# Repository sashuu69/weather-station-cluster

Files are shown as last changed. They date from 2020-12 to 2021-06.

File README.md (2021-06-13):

# Weather Station Cluster

## Introduction

The Weather Station Cluster is weather station system for ethusiasts that want to measure data for education and research purposes.

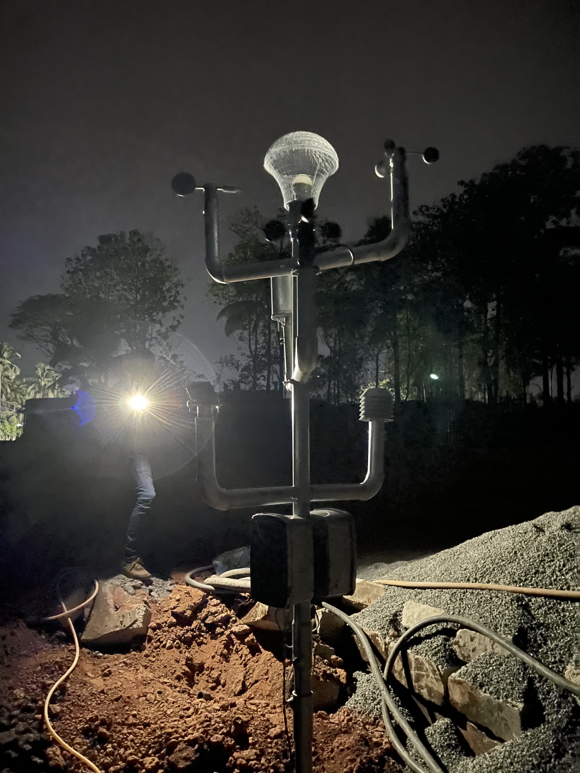
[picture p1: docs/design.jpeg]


## Features

1. The device collects the following data:-
   1. Temperature
   2. Humidity
   3. Heat index
   4. Altitude
   5. Pressure
   6. Rain (in cm)
   7. Rain duration and strength
   8. Wind speed
   9. Wind direction
2. Collects the above mentioned parameters and stores the data to database.

## Folder Structure

1. code/arduino_mega-code: Contains code for Arduino Mega.
2. code/nodemcu-code: Contains code NodeMCU.
3. docs: PCB images (Top, Bottom and Drill).
4. eagle-design: Eagle design of PCB.
5. fusion360-design: STL files of rain guage, wind direction and wind speed.

## Library used

1. DHT22 Library - [GitHub](https://github.com/adafruit/DHT-sensor-library)
2. BMP280 Library - [GitHub](https://github.com/adafruit/Adafruit_BMP280_Library)
3. RTC Library - [GitHub](https://github.com/adafruit/RTClib)
4. ArduinoJSON Library - [GitHub](https://github.com/bblanchon/ArduinoJson)
5. Adafruit Sensor - [github.com](https://github.com/adafruit/Adafruit_Sensor)

## CAD Files

1. Rain sensor support - [Thingiverse](https://www.thingiverse.com/thing:4107951)

## Components Used

1. NodeMCU (x1) - [Tomson Electronics](https://www.tomsonelectronics.com/products/buy-node-mcu-esp-8266-with-cp-2102-online)
2. Micro SD card module (x1) - [Tomson Electronics](https://www.tomsonelectronics.com/products/micro-sd-card-module)
3. Arduino Mega (x1) - [Tomson Electronics](https://www.tomsonelectronics.com/products/buy-arduino-mega-2560-online-india)
4. DHT22 (x1) - [Tomson Electronics](https://www.tomsonelectronics.com/products/dht22-digital-temperature-and-humidity-sensor-module-am2302)
5. BMP 280 (x1) - [Tomson Electronics](https://www.tomsonelectronics.com/products/bmp-280-barometer-precision-atmospheric-pressure-sensor-module)
6. Rain sensor (x1) - [Tomson Electronics](https://www.tomsonelectronics.com/products/rain-drop-detection-sensor-rain-detector-weather-module)
7. Speed Measuring sensor Groove Coupler Module (x1) - [Tomson Electronics](https://www.tomsonelectronics.com/products/speed-measuring-sensor-groove-coupler-module-for-arduino)
8. RTC module (x1) - [Tomson Electronics](https://www.tomsonelectronics.com/products/ds1307-i2c-rtc-ds1307-24c32-real-time-clock-module)
9. Button cell (CR-2032) (x1) - [Tomson Electronics](https://www.tomsonelectronics.com/products/panasonic-cr-2032)
10. Female headers - [Robu (India)](https://robu.in/product/2mm-pitch-female-berg-strip-40x1-2pcs/)
11. Male header pins - [Robu (India)](https://robu.in/product/1x40-berg-strip-male-connector/)
12. DC Barrel Power Jack (x1) - [Tomson Electronics](https://www.tomsonelectronics.com/products/dc-barrel-power-jack)
13. LED (Red) (x4) - [Tomson Electronics](https://www.tomsonelectronics.com/products/led-basic-red-5mm-pack-of-10)
14. Diode IN 4007 (x1) - [Tomson Electronics](https://www.tomsonelectronics.com/products/diode-1n-4007)
15. 7805 5V regulator (x1) - [Amazon (India)](https://www.amazon.in/5-piece-voltage-regulator-7805/dp/0070530572)
16. LED (Green) (x3) - [Tomson Electronics](https://www.tomsonelectronics.com/products/led-basic-green-5-mm)
17. Micro SD Card Module (x1) - [Tomson Electronics](https://www.tomsonelectronics.com/products/micro-sd-card-module)
18. Rain drop detection sensor Module (x1) - [Tomson Electronics](https://www.tomsonelectronics.com/products/rain-drop-detection-sensor-rain-detector-weather-module)
19. Resistor (10K Ohms) (x2) - [Tomson Electronics](https://www.tomsonelectronics.com/products/1ko-12ko-carbon-film-resistor)
20. Resistor (220 Ohms) (x7) - [Tomson Electronics](https://www.tomsonelectronics.com/products/100k-ohm-metal-film-resistor?variant=8737726038107)
21. Neodymium disc magnets (4x1.5mm) (x2) - [Tomson Electronics](https://www.tomsonelectronics.com/products/neodymium-disc-magnets?variant=37753432768707)
22. Neodymium disc magnets (4x1.5mm) (x1) - [Tomson Electronics](https://www.tomsonelectronics.com/products/neodymium-disc-magnets?variant=37753432801475)
23. PLA (1KG) (WHITE) (x1) - [Tomson Electronics](https://www.augment3di.com/product/white-pla-premium-filament-1kg/)
24. Pole, Wires, tapes and zip ties

## PCB design

### Info Board

#### Top View

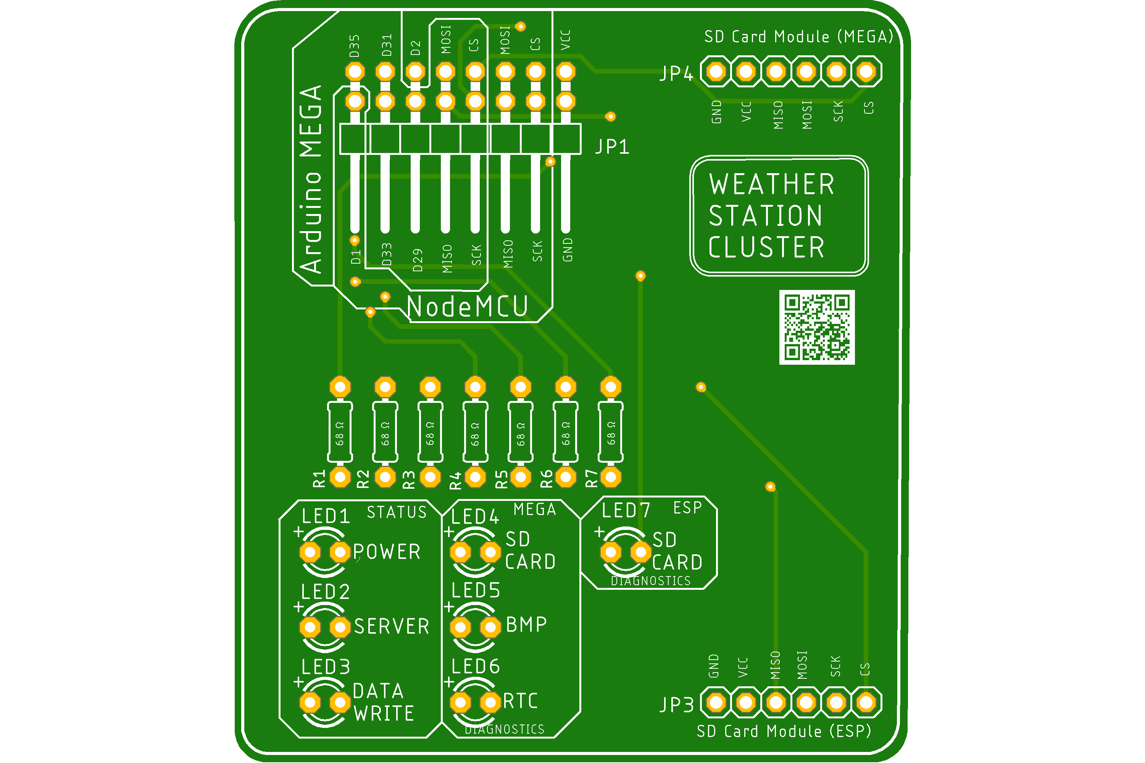
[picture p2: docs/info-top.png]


#### Bottom View

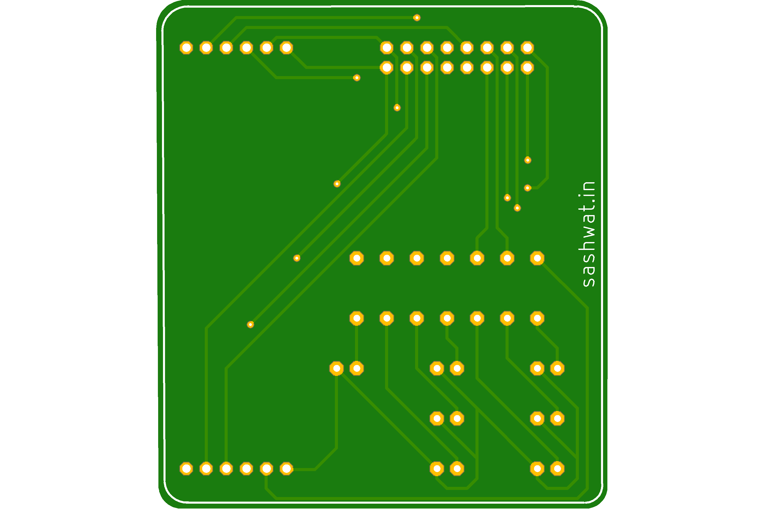
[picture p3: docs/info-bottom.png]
Bottom View


#### Drill View

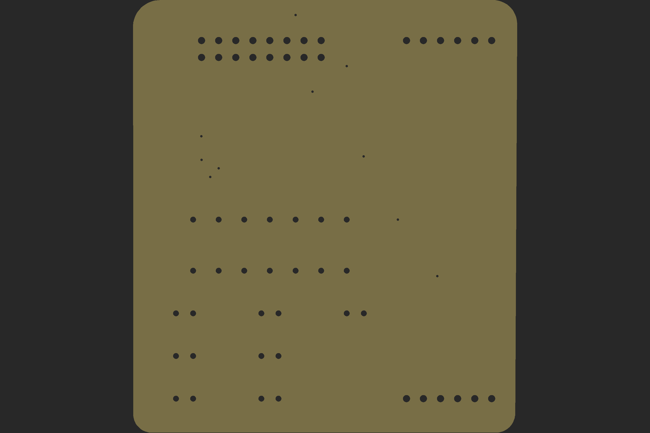
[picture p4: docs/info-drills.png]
Drill View


### Process Board

#### Top View

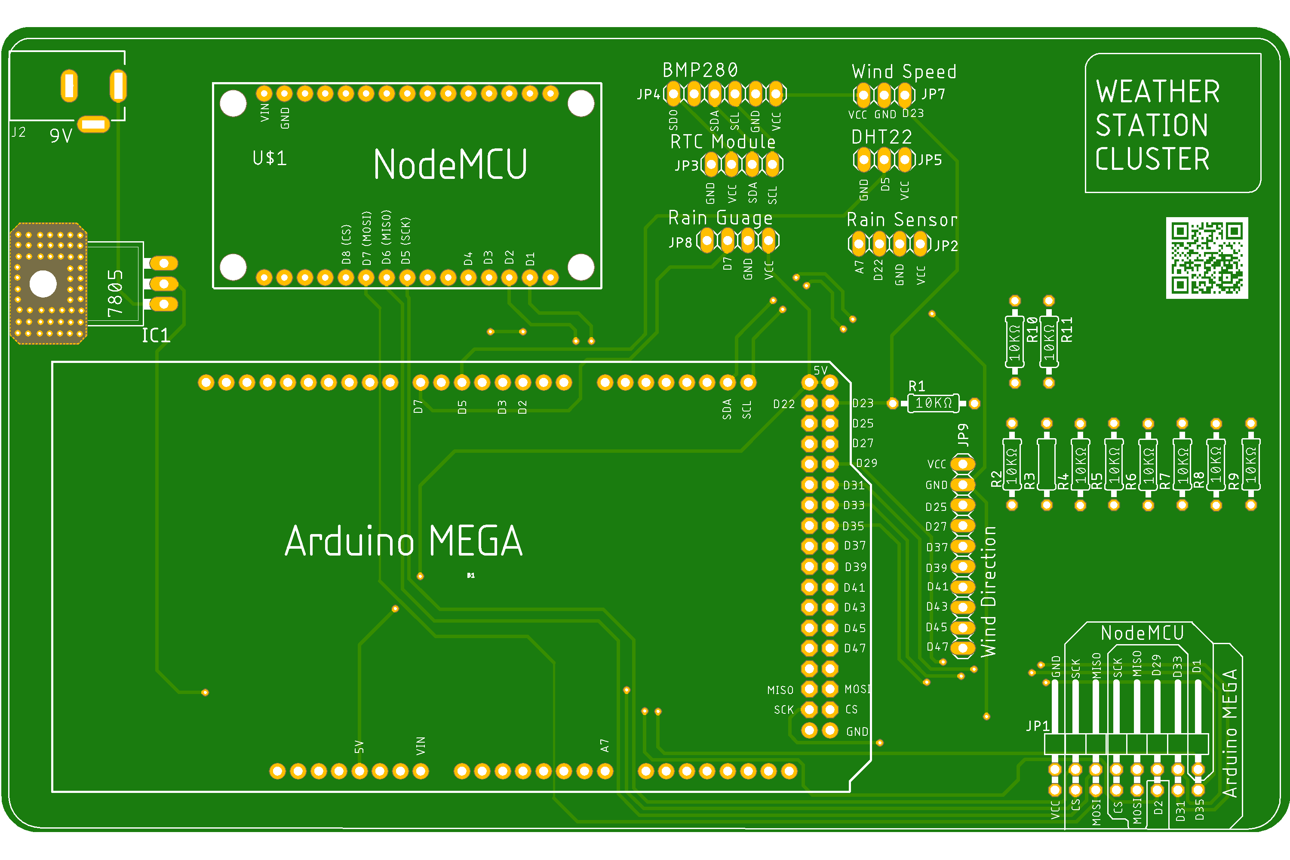
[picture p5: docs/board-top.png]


#### Bottom View

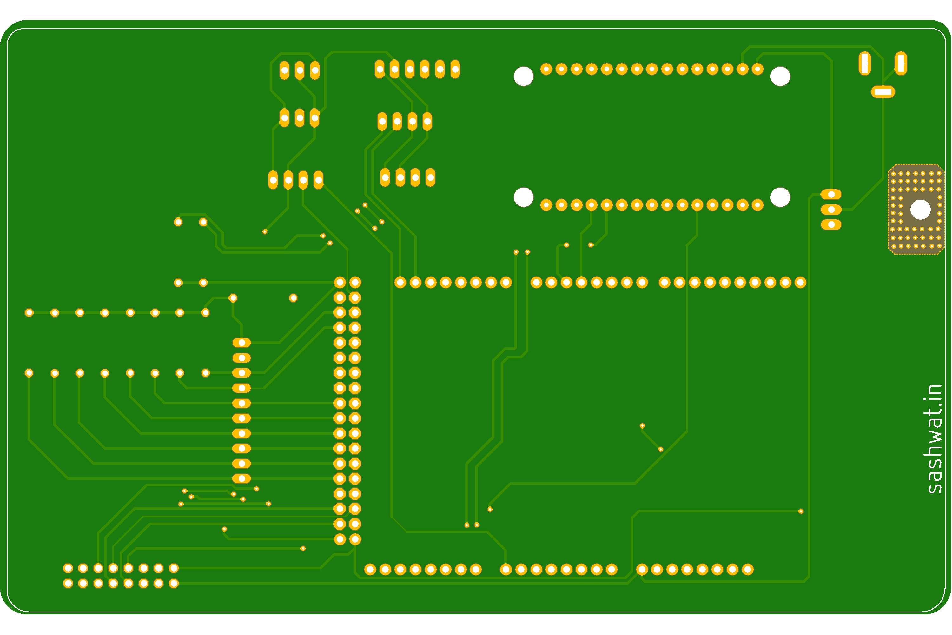
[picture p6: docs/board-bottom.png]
Bottom View


#### Drill View

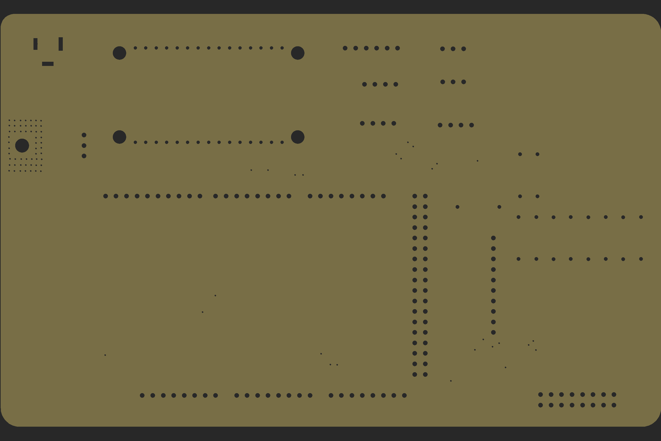
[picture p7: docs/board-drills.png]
Drill View


## Pre-Installation Steps

1. Connect the sensors as per circuit diagram.
2. Flash the NodeMCU code.
3. Connect to NodeMCU WiFi hotspot (SSID: Home Weather Station Mini) WiFi hotspot.
4. Goto http://192.168.4.1 (NodeMCU gateway).
5. Enter WiFi credentials.
6. After connecting to WiFi, use Fing to get IP address of NodeMCU.
7. Goto http://ip-address and enter username (admin) and password (pasword).
8. Enter server IP address, API key and other necessary details.

## Sensor Info

| Sensor name | Features |
| --- | --- |
| DHT22 | Temperature, Humidity and Heat Index |
| BMP280 | Temperature, atmospheric pressure and altitude |
| Rain Guage | Rain in CM |
| Rain drop sensor | Rain Duration and Strength |
| Annemometer | Wind speed and wind direction |

## Contributions

1. Sashwat K (@sashuu6) <hi@sashwat.in>
2. Tharun P Karun (@tharunpkarun) <tpk@tharun.me>
3. Sreeram (STL files) [YouTube](https://www.youtube.com/channel/UC3x_svxO5Dxl0VesjEMpuGg)

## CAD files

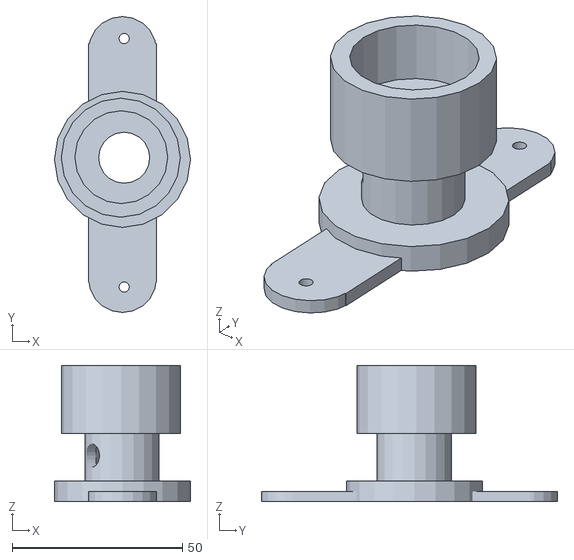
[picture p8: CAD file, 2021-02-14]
fusion360-design/rain-guage/pvc-holder.stl
40.0 x 87.0 x 40.0

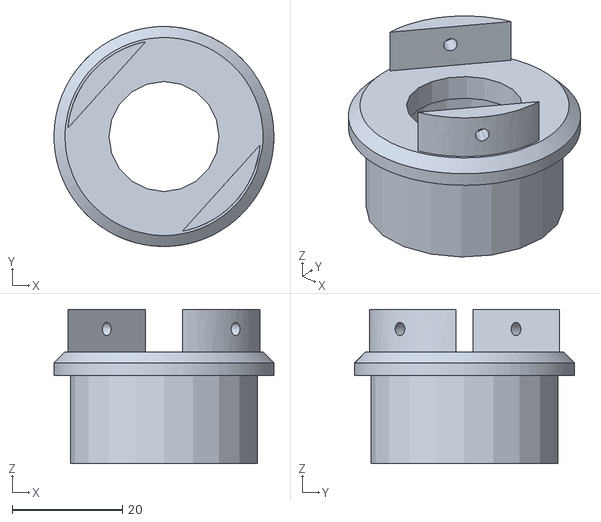
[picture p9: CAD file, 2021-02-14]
fusion360-design/wind-direction/pvc-holder.stl
40.0 x 40.0 x 28.0

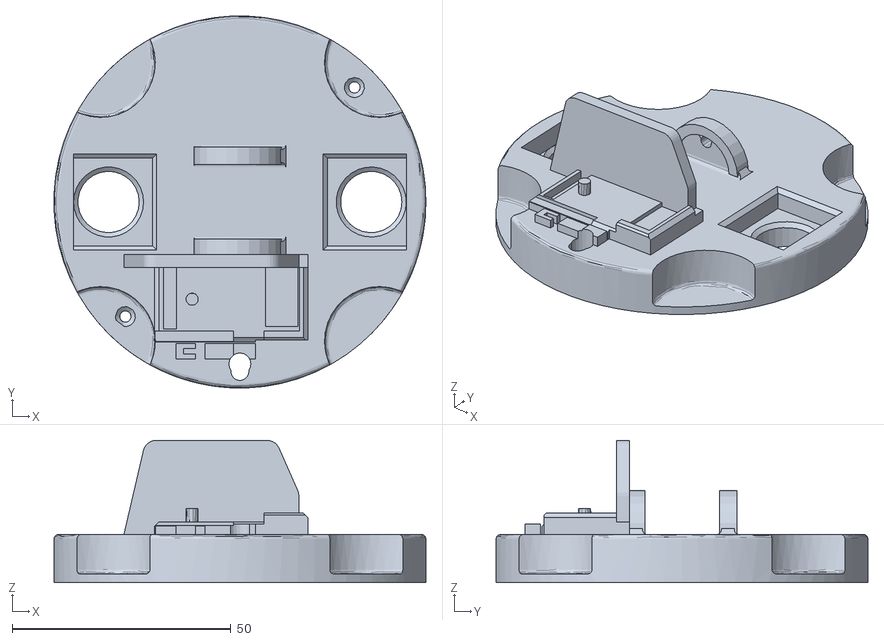
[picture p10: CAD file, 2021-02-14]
fusion360-design/rain-guage/base.stl
85.0 x 85.0 x 32.5

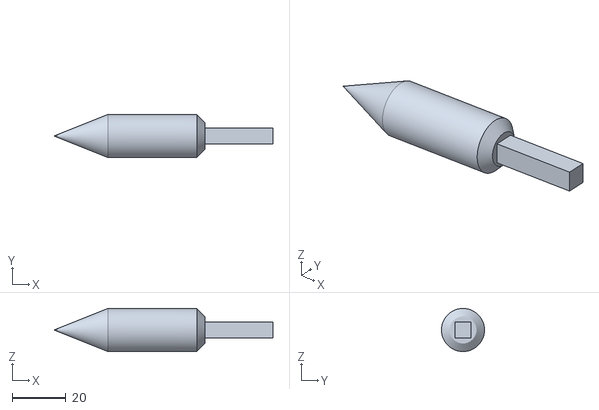
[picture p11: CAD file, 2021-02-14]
fusion360-design/wind-direction/arrow.stl
81.3 x 16.0 x 16.0

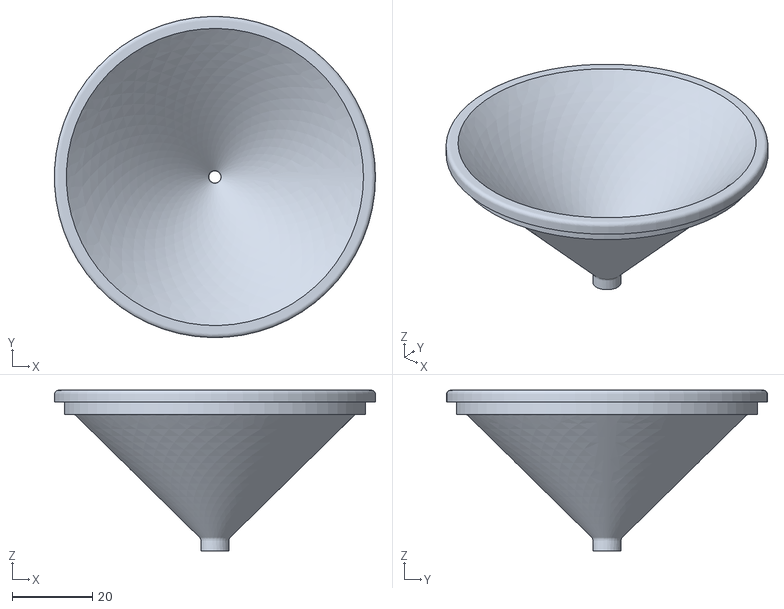
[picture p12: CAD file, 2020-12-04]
fusion360-design/rain-guage/funnel.stl
80.0 x 80.0 x 40.0

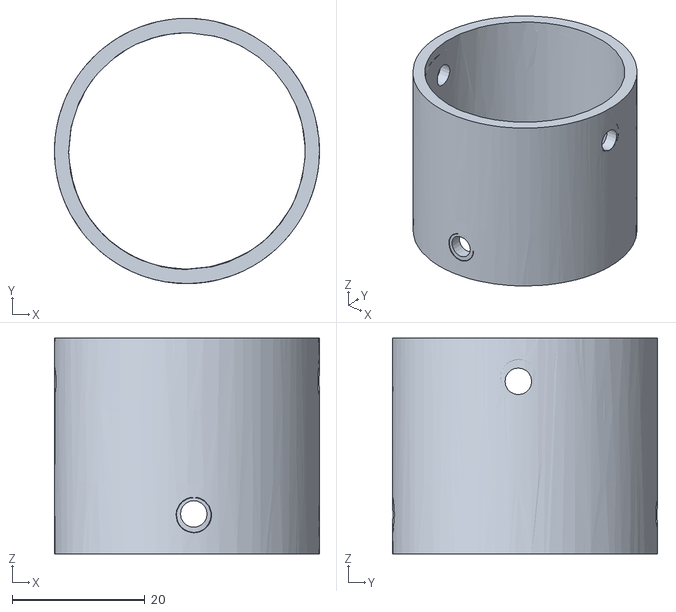
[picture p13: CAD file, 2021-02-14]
fusion360-design/wind-direction/body.stl
40.0 x 40.0 x 32.5

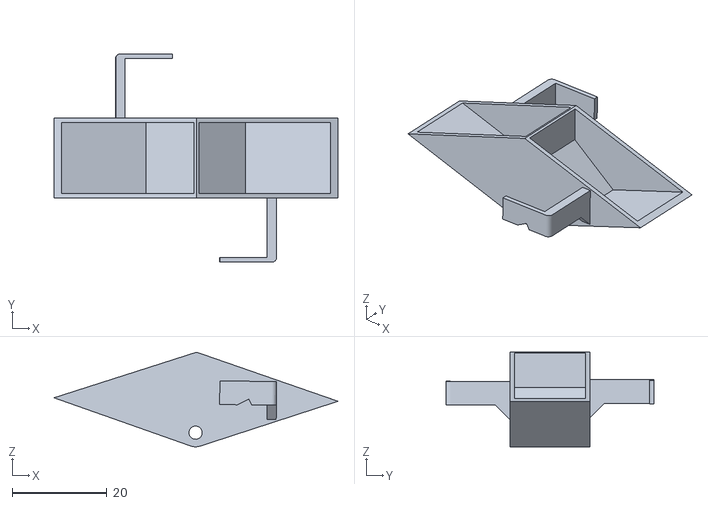
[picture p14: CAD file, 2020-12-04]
fusion360-design/rain-guage/bucket.stl
60.0 x 44.0 x 20.0

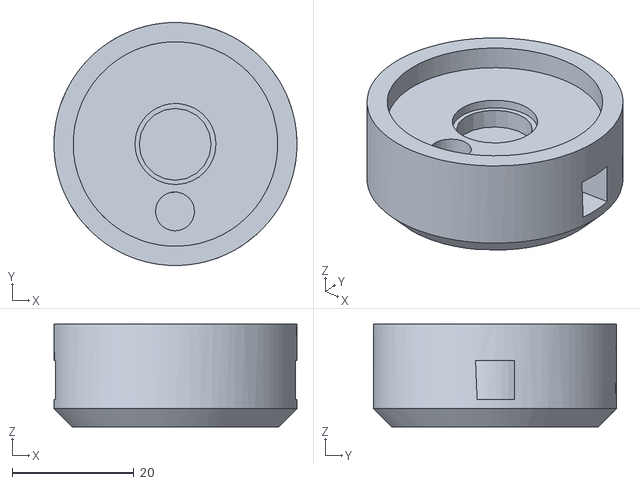
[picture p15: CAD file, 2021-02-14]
fusion360-design/wind-direction/top.stl
39.9 x 39.9 x 16.9

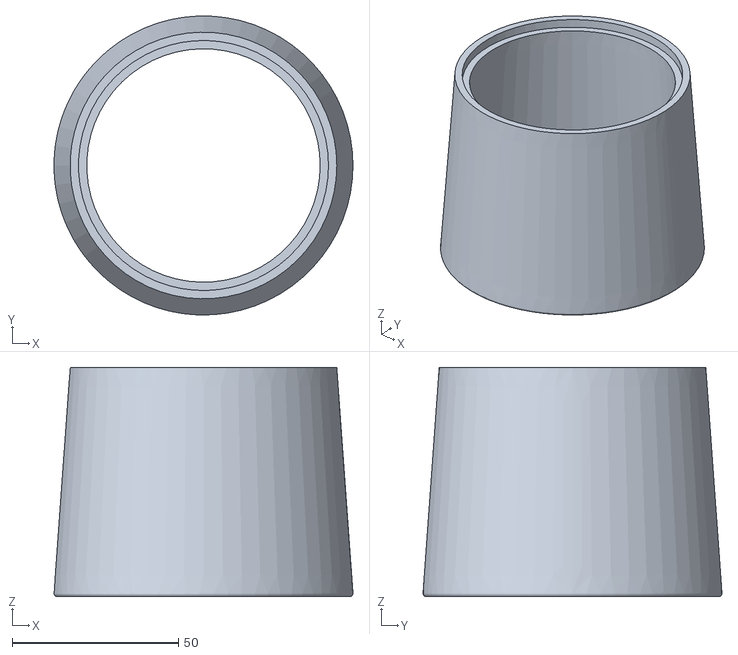
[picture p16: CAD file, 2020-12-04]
fusion360-design/rain-guage/case.stl
89.9 x 89.9 x 69.0

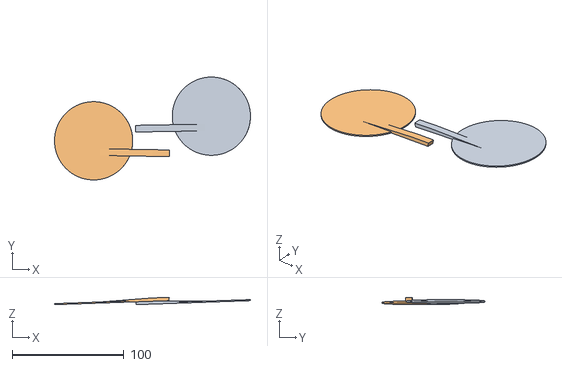
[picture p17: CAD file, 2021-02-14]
fusion360-design/wind-direction/tail.stl
175.3 x 92.0 x 6.59

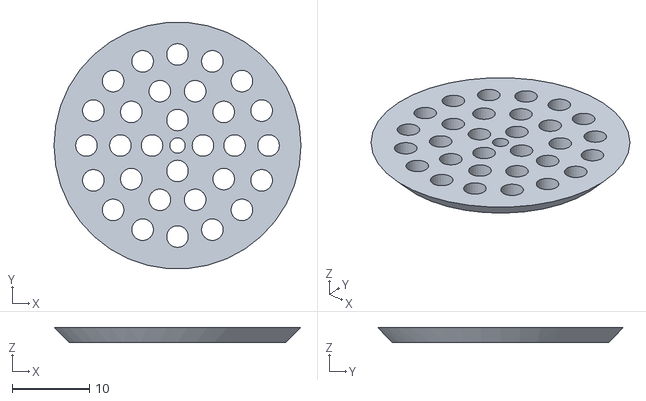
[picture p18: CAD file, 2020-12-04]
fusion360-design/rain-guage/filter.stl
32.0 x 31.9 x 2.00

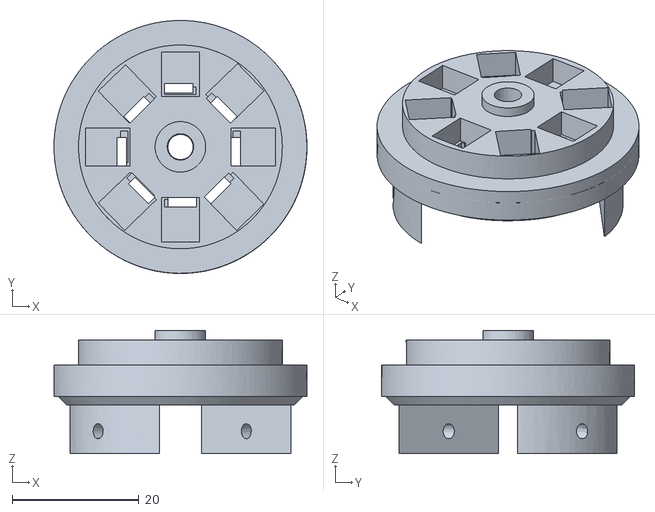
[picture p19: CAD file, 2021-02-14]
fusion360-design/wind-direction/sensor-holder.stl
40.0 x 40.0 x 19.5

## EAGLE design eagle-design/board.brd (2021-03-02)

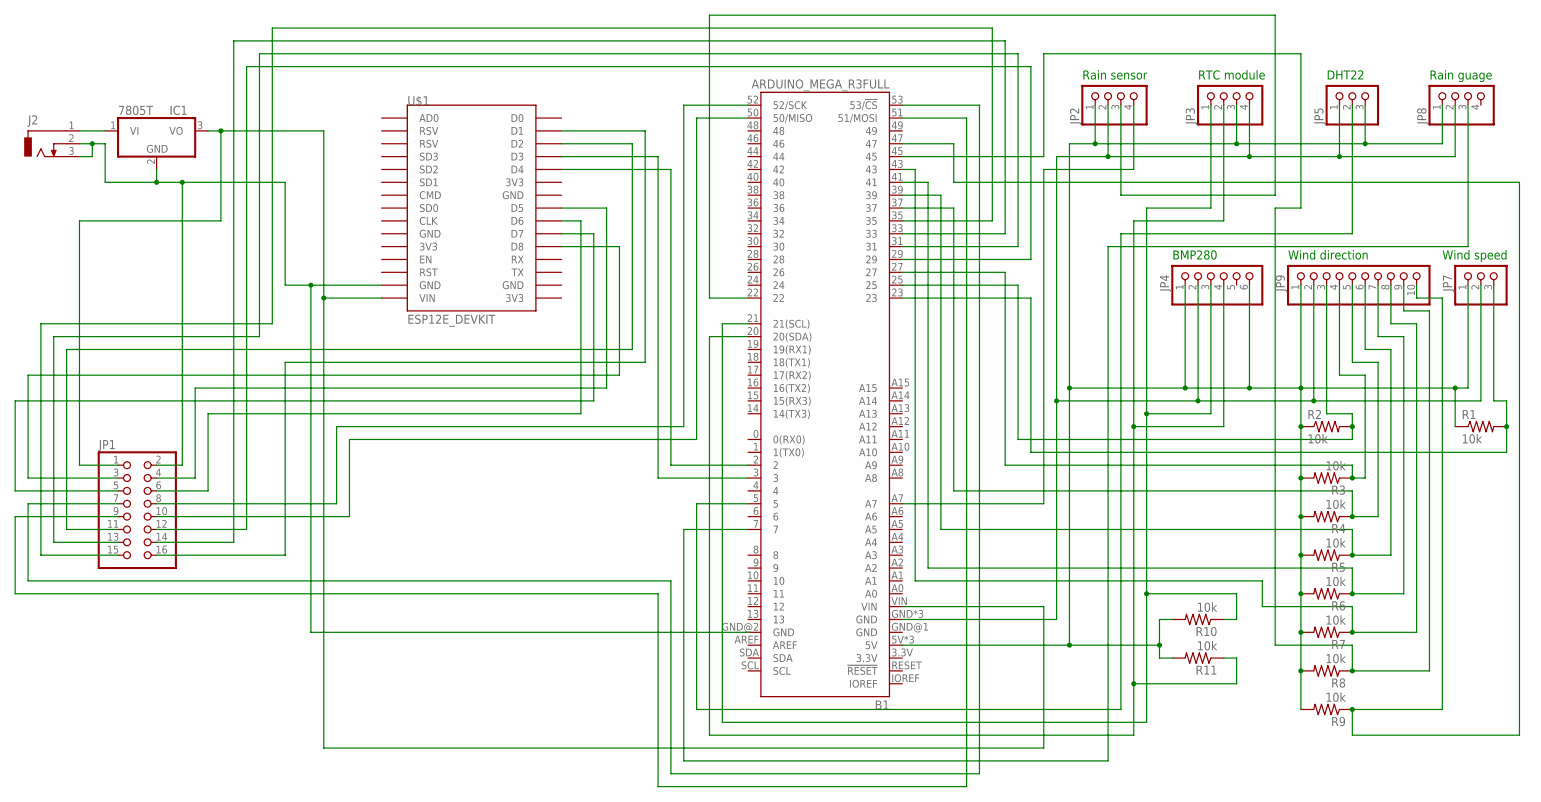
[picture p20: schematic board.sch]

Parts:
B1: ARDUINO_MEGA_R3FULL; ARDUINO_MEGA_NO_SILK
IC1: 7805T; TO220H
J2: DCJ0303
JP1: PINHD-2X8/90; 2X08/90
JP2, JP3, JP8: PINHD-1X4; 1X04
JP4: PINHD-1X6; 1X06
JP5, JP7: PINHD-1X3; 1X03
JP9: PINHD-1X10; 1X10
R1, R2, R3, R4, R5, R6, R7, R8, R9, R10, R11: 10k; 0207/10
U$1: ESP12E_DEVKIT

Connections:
unnamed: IC1.1 (VI), J2.1
unnamed: B1.GND@2 (GND), IC1.2 (GND), J2.2, J2.3, JP1.2, U$1.GND@1 (GND)
unnamed: B1.5V, B1.5V@1 (5V), B1.5V@2 (5V), JP2.1, JP3.3, JP4.1, JP4.6, JP5.3, JP7.1, JP8.1, JP9.1, R1.1, R2.1, R3.2, R4.2, R5.2, R6.2, R7.2, R8.2, R9.2, R10.2, R11.2
unnamed: B1.VIN, IC1.3 (VO), JP1.1, U$1.VIN
unnamed: B1.23, JP7.3, R1.2
unnamed: B1.GND, B1.GND@3 (GND), B1.GND@4 (GND), JP2.2, JP3.4, JP4.2, JP5.1, JP7.2, JP8.2, JP9.2
unnamed: B1.A7, JP2.4
unnamed: B1.2, U$1.D4
unnamed: B1.5, JP5.2
unnamed: B1.7, JP8.3
unnamed: B1.33, JP1.14
unnamed: B1.3, U$1.D3
unnamed: JP1.11, U$1.D2
unnamed: B1.29, JP1.12
unnamed: B1.31, JP1.13
unnamed: B1.35, JP1.15
unnamed: JP1.16, U$1.D1
unnamed: JP1.6, U$1.D6
unnamed: JP1.3, U$1.D8
unnamed: JP1.4, U$1.D5
unnamed: B1.53 (53/!CS), JP1.7
unnamed: JP1.5, U$1.D7
unnamed: B1.52 (52/SCK), JP1.8
unnamed: B1.51 (51/MOSI), JP1.9
unnamed: B1.25, JP9.3, R2.2
unnamed: B1.50 (50/MISO), JP1.10
unnamed: B1.27, JP9.4, R3.1
unnamed: B1.37, JP9.5, R4.1
unnamed: B1.39, JP9.6, R5.1
unnamed: B1.41, JP9.7, R6.1
unnamed: B1.43, JP9.8, R7.1
unnamed: B1.45, JP9.9, R8.1
unnamed: B1.47, JP9.10, R9.1
unnamed: B1.22, JP2.3
unnamed: B1.21 (21(SCL)), JP3.1, JP4.3, R10.1
unnamed: B1.20 (20(SDA)), JP3.2, JP4.4, R11.1

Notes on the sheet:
Rain sensor
RTC module
DHT22
BMP280
Wind direction
Wind speed
Rain guage

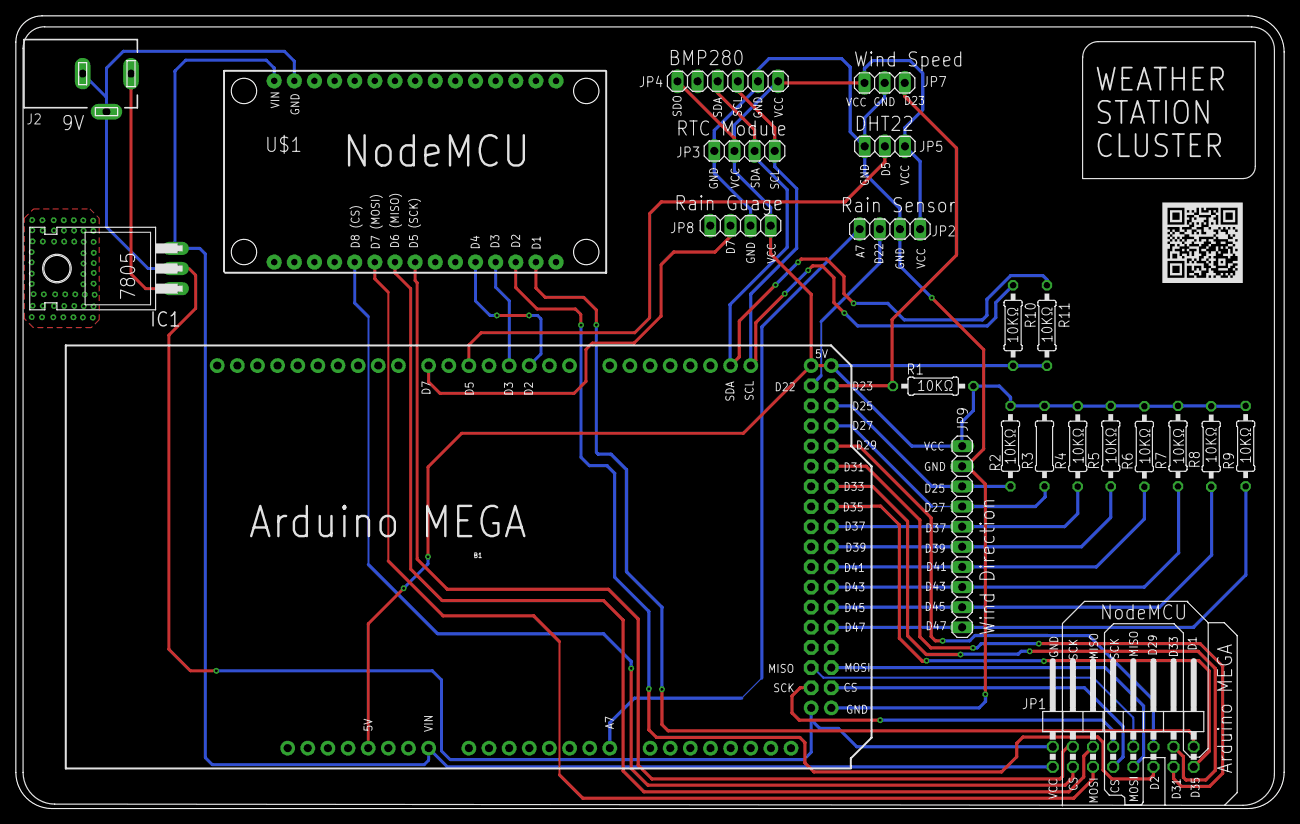
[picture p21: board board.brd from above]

Board: 2 copper layers, 160.0 x 100.0 mm, 23 parts (0 on the bottom side), 36 nets.

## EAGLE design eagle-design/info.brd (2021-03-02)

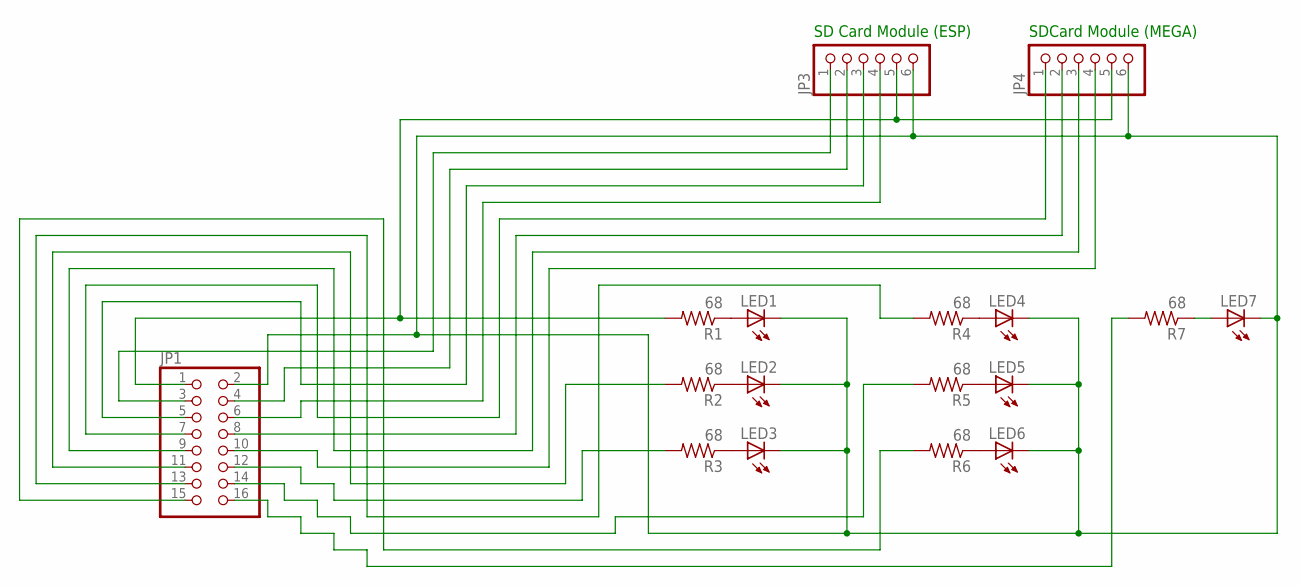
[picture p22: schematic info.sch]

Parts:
JP1: PINHD-2X8/90; 2X08/90
JP3, JP4: PINHD-1X6; 1X06
LED1, LED2, LED3, LED4, LED5, LED6, LED7: LED3MM
R1, R2, R3, R4, R5, R6, R7: 68; 0204/7

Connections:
unnamed: LED4.A, R4.1
unnamed: LED5.A, R5.1
unnamed: LED6.A, R6.1
unnamed: LED7.A, R7.1
unnamed: LED1.A, R1.1
unnamed: LED2.A, R2.1
unnamed: LED3.A, R3.1
unnamed: JP1.10, JP4.4
unnamed: JP1.2, JP3.6, JP4.6, LED1.K (C), LED2.K (C), LED3.K (C), LED4.K (C), LED5.K (C), LED6.K (C), LED7.K (C)
unnamed: JP1.11, R2.2
unnamed: JP1.1, JP3.5, JP4.5, R1.2
unnamed: JP1.3, JP3.1
unnamed: JP1.4, JP3.2
unnamed: JP1.5, JP3.3
unnamed: JP1.6, JP3.4
unnamed: JP1.7, JP4.1
unnamed: JP1.8, JP4.2
unnamed: JP1.9, JP4.3
unnamed: JP1.12, R3.2
unnamed: JP1.13, R4.2
unnamed: JP1.14, R5.2
unnamed: JP1.15, R6.2
unnamed: JP1.16, R7.2

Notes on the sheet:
SD Card Module (ESP)
SDCard Module (MEGA)

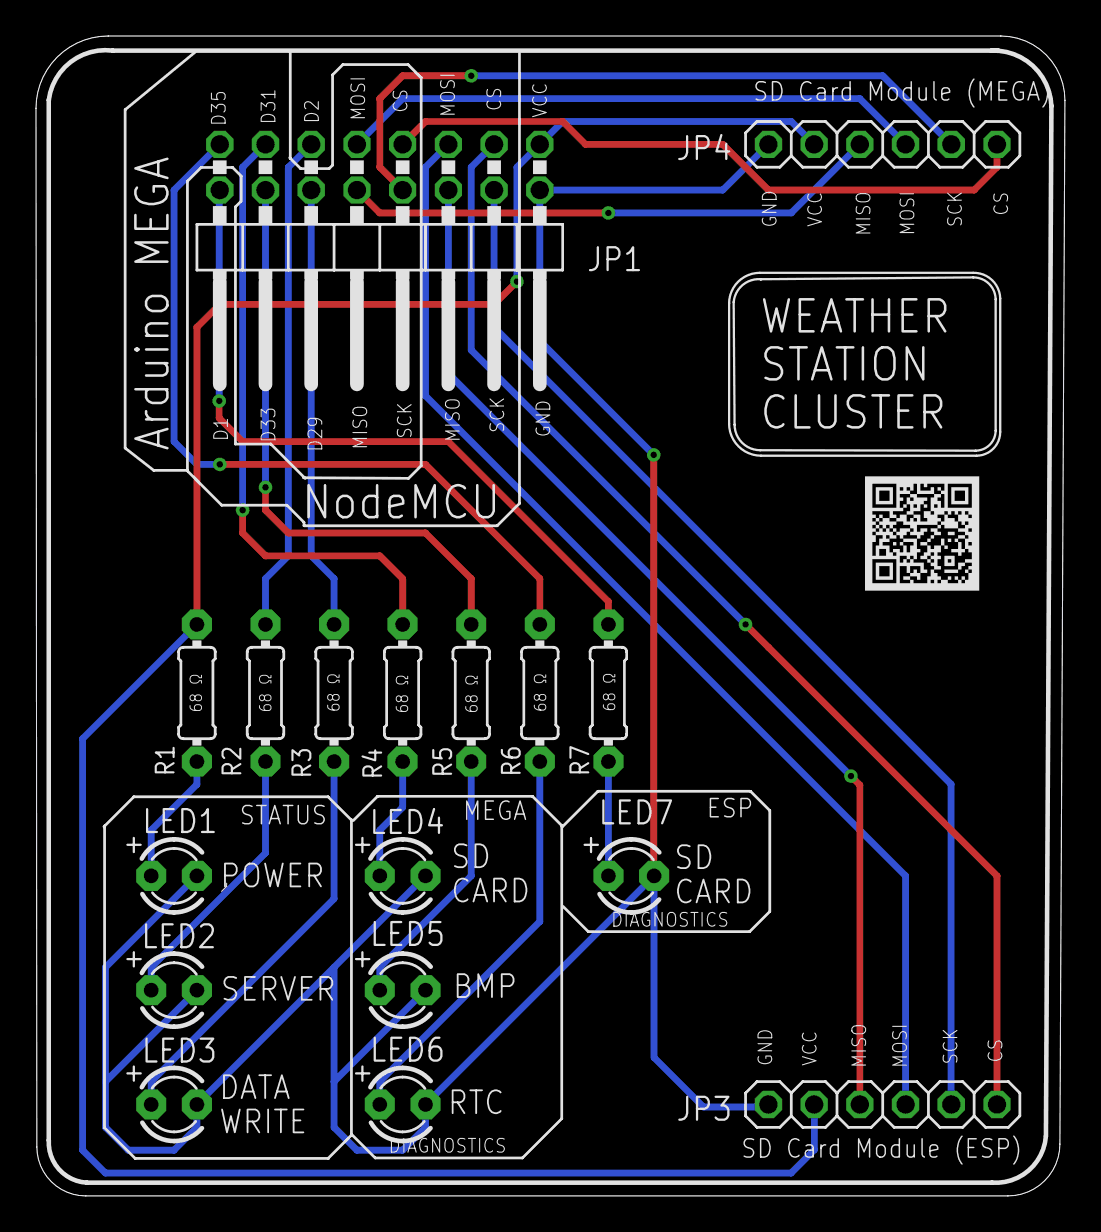
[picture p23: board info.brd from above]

Board: 2 copper layers, 57.2 x 64.4 mm, 17 parts (0 on the bottom side), 23 nets.

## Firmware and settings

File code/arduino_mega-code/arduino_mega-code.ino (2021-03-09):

/*
 * Project Name: Weather Station Cluster
 * Program Name: Arduino Mega code
 * Board Name : Arduino Mega
 * Created on: 13/12/2020 08:04:00 PM
 * Last Modified: 09/03/2021 10:35:00 PM
 * Created by: Sashwat K
 */

// JSON connection
#include "ArduinoJson.h"

// Software Serial
#include <SoftwareSerial.h> // Library for Software Serial
SoftwareSerial s_serial_to_esp(3, 2); //RX, TX

// DHT22
#include "DHT.h"
#define DHTPIN 5
#define DHTTYPE DHT22
DHT dht(DHTPIN, DHTTYPE);

// BMP280
#include <Wire.h>
#include <SPI.h>
#include <Adafruit_BMP280.h>
Adafruit_BMP280 bmp;

// Rain Sensor
#define RAINSENSORANALOGPIN A7
#define RAINSENSORDIGITALPIN  22

// Rain Guage
#define RAINGUAGEPIN 7
int rain_guage_counter = 0;
int rain_guage_flag = 0;
int rain_guage_data = 0;

// Wind Speed
#define WINDSPEEDPIN 23

// Wind Direction
#define WINDDIRN 25
#define WINDDIRNE 27
#define WINDDIRE 37
#define WINDDIRSE 39
#define WINDDIRS 41
#define WINDDIRSW 43
#define WINDDIRW 45
#define WINDDIRNW 47

// RTC Module
#include <RTClib.h>
RTC_DS1307 rtc;

// Micro SD card Module
#include <SPI.h>
#include <SD.h>
File sd_card;
int sdcard_chip_select = 53;

// LEDs
#define SDREADLEDPIN 29 
#define BMPERRLEDPIN 33
#define RTCERRLEDPIN 31
#define SDCRDERRLEDPIN 35

// Global counter
int counter = 0;
bool sdcard_flag = false;

void setup() {
  // put your setup code here, to run once:
  Serial.begin(9600);
  Serial.println("-------------------------");
  Serial.println(" Weather Station Cluster ");
  Serial.println("-------------------------");
  Serial.println("Sensor Initialisation \n");

  // Initialise LEDs
  pinMode(SDREADLEDPIN, OUTPUT);
  pinMode(BMPERRLEDPIN, OUTPUT);
  pinMode(RTCERRLEDPIN, OUTPUT);
  pinMode(SDCRDERRLEDPIN, OUTPUT);

  // Initialise LED to off
  digitalWrite(SDREADLEDPIN, LOW);
  digitalWrite(BMPERRLEDPIN, LOW);
  digitalWrite(RTCERRLEDPIN, LOW);
  digitalWrite(SDCRDERRLEDPIN, LOW);
  
  // Initialise DHT22
  Serial.print("1. Initialising DHT22");
  dht.begin();
  Serial.println("\t Success");

  // Initialise BMP280
  Serial.print("2. Initialising BMP280");
  int bmp_lib = bmp.begin();
  if(!bmp_lib){
    digitalWrite(BMPERRLEDPIN, HIGH);
    Serial.println("\t Failed");
    Serial.flush();
    abort();
  }
  else {
    Serial.println("\t Success");
  }

  // Initialise RTC module
  Serial.print("3. Initialising RTC module");
  if (! rtc.begin()) {
    digitalWrite(RTCERRLEDPIN, HIGH);
    Serial.println("\t Failed");
    Serial.flush();
    abort();
  }
  else {
    Serial.println("\t Success");
  }

  Serial.print("4. Initialising Micro SD card module");
  pinMode(sdcard_chip_select, OUTPUT);
  if (!SD.begin()) {
    digitalWrite(SDCRDERRLEDPIN, HIGH);
    Serial.println("\t Failed");
    while (1);
  }
  else {
    Serial.println("\t Success");
  }

  Serial.print("5. Initialising Rain sensor");
  // Initialise rain sensor
  pinMode(INPUT, RAINSENSORANALOGPIN);
  pinMode(INPUT, RAINSENSORDIGITALPIN);
  Serial.println("\t Success");

  Serial.print("6. Initialising Rain guage");
  // Initialise rain guage
  pinMode(INPUT, RAINGUAGEPIN);
  Serial.println("\t Success");

  // Initialise Wind speed
  Serial.print("7. Initialising Wind speed sensor");
  pinMode(INPUT, WINDSPEEDPIN);
  Serial.println("\t Success");

  // Initialise Wind direction
  Serial.print("8. Initialising Wind direction sensor");
  pinMode(INPUT, WINDDIRN);
  pinMode(INPUT, WINDDIRNE);
  pinMode(INPUT, WINDDIRE);
  pinMode(INPUT, WINDDIRSE);
  pinMode(INPUT, WINDDIRS);
  pinMode(INPUT, WINDDIRSW);
  pinMode(INPUT, WINDDIRW);
  pinMode(INPUT, WINDDIRNW);
  Serial.println("\t Success");

  // Begin software Serial
  Serial.print("9. Initialising software serial");
  s_serial_to_esp.begin(4800);
  Serial.println("\t Success");
  
  Serial.println("\ninitialiaation complete");
  Serial.println("-------------------------\n");

  Serial.println("Post Initialisation steps");
  Serial.println("-------------------------\n");

  // BMP post initialisation
  Serial.println("Setting BMP settings");
  bmp.setSampling(Adafruit_BMP280::MODE_NORMAL,     /* Operating Mode. */
                    Adafruit_BMP280::SAMPLING_X2,     /* Temp. oversampling */
                    Adafruit_BMP280::SAMPLING_X16,    /* Pressure oversampling */
                    Adafruit_BMP280::FILTER_X16,      /* Filtering. */
                    Adafruit_BMP280::STANDBY_MS_500); /* Standby time. */

  // RTC module
  if (! rtc.isrunning()) {
    Serial.println("RTC is NOT running, let's set the time!");
    rtc.adjust(DateTime(F(__DATE__), F(__TIME__)));
  }
}

void loop() {
  // put your main code here, to run repeatedly:

  // Read data from DHT22
  float dht_humidity = dht.readHumidity();
  float dht_temperature = dht.readTemperature();
  float dht_heat_index = dht.computeHeatIndex(dht_temperature, dht_humidity, false);

  // Read data from BMP280
  double bmp_temperature = bmp.readTemperature();
  /* bmp_pressure = pressure_value / 100 + const
   * const = 1018.33 - (get pressure value of your location from https://en.allmetsat.com/metar-taf/)
   * Thiruvananthapuram, Kerala, India - https://en.allmetsat.com/metar-taf/india-sri-lanka.php?icao=VOTV
   */
  double bmp_pressure = bmp.readPressure() / 100.00 + (1018.33 - 1012);
  double bmp_altitude = bmp.readAltitude(bmp_pressure);

  // Read data from RTC module
  DateTime now = rtc.now();
  String rtc_day = (now.day()>9)?String(now.day()):"0" + String(now.day());
  String rtc_month = (now.month()>9)?String(now.month()):"0" + String(now.month());
  String rtc_year = String(now.year());
  String rtc_hour = (now.hour()>9)?String(now.hour()):"0" + String(now.hour());
  String rtc_minutes = (now.minute()>9)?String(now.minute()):"0" +String(now.minute());
  String rtc_seconds = (now.second()>9)?String(now.second()):"0" +String(now.second());

  // Read data from Rain Sensor
  int rain_sensor_data_analog = analogRead(RAINSENSORANALOGPIN);
  int rain_sensor_data_digital = digitalRead(RAINSENSORDIGITALPIN);
  
  int rain_guage_output = digitalRead(RAINGUAGEPIN);
  if(rain_guage_flag != rain_guage_output) {
    rain_guage_data ++;
    rain_guage_flag = rain_guage_output;
  }

  // Reset rain guage every midnight
  if (now.hour() == 0 && now.minute() == 00) {
    rain_guage_data = 0;
  }

  // Get wind direction
  int wind_direction_n = digitalRead(WINDDIRN);
  int wind_direction_ne = digitalRead(WINDDIRNE);
  int wind_direction_e = digitalRead(WINDDIRE);
  int wind_direction_se = digitalRead(WINDDIRSE);
  int wind_direction_s = digitalRead(WINDDIRS);
  int wind_direction_sw = digitalRead(WINDDIRSW);
  int wind_direction_w = digitalRead(WINDDIRW);
  int wind_direction_nw = digitalRead(WINDDIRNW);

  String wind_direction_data;

  if (wind_direction_n == HIGH) {
    wind_direction_data = "North";
  }
  else if (wind_direction_ne == HIGH) {
    wind_direction_data = "North EAST";
  }
  else if (wind_direction_e == HIGH) {
    wind_direction_data = "EAST";
  }
  else if (wind_direction_se == HIGH) {
    wind_direction_data = "South East";
  }
  else if (wind_direction_s == HIGH) {
    wind_direction_data = "South";
  }
  else if (wind_direction_sw == HIGH) {
    wind_direction_data = "South West";
  }
  else if (wind_direction_w == HIGH) {
    wind_direction_data = "West";
  }
  else if (wind_direction_nw == HIGH) {
    wind_direction_data = "North West";
  }

  // Create JSON data
  DynamicJsonDocument doc(1024);
  doc["rtc_day"] = rtc_day;
  doc["rtc_month"] = rtc_month;
  doc["rtc_year"] = rtc_year;
  doc["rtc_hour"] = rtc_hour;
  doc["rtc_minutes"] = rtc_minutes;
  doc["rtc_seconds"] = rtc_seconds;
  doc["dht_humidity"] = dht_humidity;
  doc["dht_temperature"] = dht_temperature;
  doc["dht_heat_index"] = dht_heat_index;
  doc["bmp_temperature"] = bmp_temperature;
  doc["bmp_pressure"] = bmp_pressure;
  doc["bmp_altitude"] = bmp_altitude;
  doc["rain_sensor_data_analog"] = rain_sensor_data_analog;
  doc["rain_sensor_data_digital"] = rain_sensor_data_digital;
  doc["rain_guage_data"] = rain_guage_data;
  //doc["wind_speed"] =
  doc["wind_direction"] = wind_direction_data;
  
  // Send JSON via Serial
  serializeJson(doc, s_serial_to_esp);
  doc.clear();

  // Store data in micro sdcard every 5 seconds
  if (counter % 30 == 0) {
    String final_string = rtc_day + "-" + rtc_month + "-" + rtc_year + "," + 
                          rtc_hour + ":" + rtc_minutes + ":" + rtc_seconds + "," + 
                          dht_humidity + "," + dht_temperature + "," + dht_heat_index + "," + 
                          bmp_temperature + "," + bmp_pressure + "," + bmp_altitude + "," + 
                          rain_sensor_data_analog + "," + rain_sensor_data_digital + "," + 
                          rain_guage_data;
                          
    sd_card = SD.open("sdt.txt", FILE_WRITE);
    sd_card.println(final_string);
    sd_card.close();
    counter = 0;
    sdcard_flag = true;
  }
  counter ++;

  if (sdcard_flag == true) {
    if (counter == 1) {
      digitalWrite(SDREADLEDPIN, HIGH);
    }
    else if (counter == 2) {
      digitalWrite(SDREADLEDPIN, LOW);
      sdcard_flag = false;
    }
  }

  // Serial print for debugging
  Serial.println("-----------------------------------");
  Serial.print("1. RTC Date: "); Serial.print(rtc_day);Serial.print("-");Serial.print(rtc_month);Serial.print("-");Serial.println(rtc_year);
  Serial.print("2. RTC Time: "); Serial.print(rtc_hour);Serial.print(":");Serial.print(rtc_minutes);Serial.print(":");Serial.println(rtc_seconds);
  Serial.print("3. DHT22 Humidity: "); Serial.print(dht_humidity); Serial.println(" %");
  Serial.print("4. DHT22 Temperature: "); Serial.print(dht_temperature); Serial.println(" °C");
  Serial.print("5. DHT22 Heat Index: "); Serial.print(dht_heat_index); Serial.println(" °C");
  Serial.print("6. BMP280 Temperature: "); Serial.print(bmp_temperature); Serial.println(" °C");
  Serial.print("7. BMP280 Pressure: "); Serial.print(bmp_pressure); Serial.println(" mbar");
  Serial.print("8. BMP Altitude: "); Serial.print(bmp_altitude); Serial.println(" m");
  Serial.print("9. Rain Sensor (Analog): "); Serial.println(rain_sensor_data_analog);
  Serial.print("10. Rain Sensor (Digital): "); Serial.println(rain_sensor_data_digital);
  Serial.print("11. Rain Guage: "); Serial.println(rain_guage_data);
  Serial.print("12. Wind Speed: "); Serial.print(""); Serial.println(" m/s");
  Serial.print("13. Wind direction: "); Serial.println();
  Serial.println("-----------------------------------\n");
  delay(1000);
}

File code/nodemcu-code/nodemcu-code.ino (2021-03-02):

/*
 * Project Name: Weather Station Cluster
 * Program Name: NodeMCU code
 * Created on: 20/11/2020 02:11:00 AM
 * Last Modified: 27/02/2021 03:51:00 PM
 * Created by: Sashwat K
 */

// WiFi manager & server
#include <ESP8266WiFi.h>
#include <ESP8266mDNS.h>
#include <WiFiUdp.h>
#include <ArduinoOTA.h>
#include <DNSServer.h>
#include <ESP8266WebServer.h>
#include <WiFiManager.h> 
#define WEB_PORT 80

WiFiManager wifiManager;
ESP8266WebServer server(WEB_PORT);
WiFiClient client;

// Micro SD card Module
#include <SPI.h>
#include <SD.h>
File sd_card;
#define CS_PIN  15

// JSON connection
#include "ArduinoJson.h"

// Software Serial
#include <SoftwareSerial.h> // Library for Software Serial
SoftwareSerial s_serial_to_mega(2,0); //RX, TX

// LED - D4 - GPIO2
#define SDCRDERRLEDPIN 2

String admin_username = "admin";
String admin_password;
String server_url;
String server_api_key;
String gps_longitude;
String gps_latitude;

int timer = 0;
int addr = 0;

// Store serial data from Software Serial
float dht_humidity_global;
float dht_temperature_global;
float dht_heat_index_global;
double bmp_temperature_global;
double bmp_pressure_global;
double bmp_altitude_global;
String rtc_day_global;
String rtc_month_global;
String rtc_year_global;
String rtc_hour_global;
String rtc_minutes_global;
String rtc_seconds_global;
int rain_sensor_data_analog_global;
int rain_sensor_data_digital_global;
int rain_guage_data_global;

void setup() {
  // put your setup code here, to run once:
  Serial.begin(9600);
  Serial.println("-------------------------");
  Serial.println(" Weather Station Cluster ");
  Serial.println("-------------------------");
  Serial.println("Sensor Initialisation \n");

  // Initialise LED
  pinMode(SDCRDERRLEDPIN, OUTPUT);

  // Initialise LED to off
  digitalWrite(SDCRDERRLEDPIN, LOW);

  Serial.print("1. Initialising SD card module");
  if (!SD.begin(CS_PIN)) {
    digitalWrite(SDCRDERRLEDPIN, HIGH);
    Serial.println("\t Failed");
    while (1);
  }
  else {
    Serial.println("\t Success");
  }

  wifiManager.autoConnect("Weather Station Cluster");

  ArduinoOTA.setPort(8266);
  ArduinoOTA.setHostname("Weather Station Cluster");

  ArduinoOTA.onStart([]() {
    String type;
    if (ArduinoOTA.getCommand() == U_FLASH) {
      type = "sketch";
    } else { // U_FS
      type = "filesystem";
    }

    // NOTE: if updating FS this would be the place to unmount FS using FS.end()
    Serial.println("Start updating " + type);
  });
  ArduinoOTA.onEnd([]() {
    Serial.println("\nEnd");
  });
  ArduinoOTA.onProgress([](unsigned int progress, unsigned int total) {
    Serial.printf("Progress: %u%%\r", (progress / (total / 100)));
  });
  ArduinoOTA.onError([](ota_error_t error) {
    Serial.printf("Error[%u]: ", error);
    if (error == OTA_AUTH_ERROR) {
      Serial.println("Auth Failed");
    } else if (error == OTA_BEGIN_ERROR) {
      Serial.println("Begin Failed");
    } else if (error == OTA_CONNECT_ERROR) {
      Serial.println("Connect Failed");
    } else if (error == OTA_RECEIVE_ERROR) {
      Serial.println("Receive Failed");
    } else if (error == OTA_END_ERROR) {
      Serial.println("End Failed");
    }
  });
  ArduinoOTA.begin();
  
  server.on("/", handle_OnConnect);
  server.on("/change_hostname", change_hostname);
  server.on("/change_server_ip", change_server_ip);
  server.on("/change_api_key", change_api_key);
  server.on("/change_lattitude", change_lattitude);
  server.on("/change_longitude", change_longitude);
  server.on("/change_admin_password", change_admin_password);
  server.on("/reset_network", reset_network);
  server.on("/reset_everything", reset_everything);
  server.onNotFound(handleNotFound);
  server.begin();
  
  Serial.println("Home weather station connected.");

  s_serial_to_mega.begin(4800);
  Serial.println("Initialisation complete");
  Serial.println("--------------------------------");
}

void loop() {
  // put your main code here, to run repeatedly:
  if (s_serial_to_mega.available()) {
    DynamicJsonDocument doc(1024);
    DeserializationError err = deserializeJson(doc, s_serial_to_mega);
    if (err == DeserializationError::Ok) {
      float dht_humidity = doc["dht_humidity"];
      float dht_temperature = doc["dht_temperature"];
      float dht_heat_index = doc["dht_heat_index"];
      double bmp_temperature = doc["bmp_temperature"];
      double bmp_pressure = doc["bmp_pressure"];
      double bmp_altitude = doc["bmp_altitude"];
      String rtc_day = doc["rtc_day"];
      String rtc_month = doc["rtc_month"];
      String rtc_year = doc["rtc_year"];
      String rtc_hour = doc["rtc_hour"];
      String rtc_minutes = doc["rtc_minutes"];
      String rtc_seconds = doc["rtc_seconds"];
      int rain_sensor_data_analog = doc["rain_sensor_data_analog"];
      int rain_sensor_data_digital = doc["rain_sensor_data_digital"];
      int rain_guage_data = doc["rain_guage_data"];
      Serial.println(dht_humidity);

      // ArduinoJSON Library bug, needs spliting
      dht_humidity_global = dht_humidity;
      dht_temperature_global = dht_temperature;
      dht_heat_index_global = dht_heat_index;
      bmp_temperature_global = bmp_temperature;
      bmp_pressure_global = bmp_pressure;
      bmp_altitude_global = bmp_altitude; 
      rtc_day_global = rtc_day;
      rtc_month_global = rtc_month;
      rtc_year_global = rtc_year;
      rtc_hour_global = rtc_hour;
      rtc_minutes_global = rtc_minutes;
      rtc_seconds_global = rtc_seconds;
      rain_sensor_data_analog_global = rain_sensor_data_analog;
      rain_sensor_data_digital_global = rain_sensor_data_digital;
      rain_guage_data_global = rain_guage_data;
      
      Serial.println("--------------------------------------------");
      Serial.print("1. Humidity (DHT22): ");Serial.println(dht_humidity);
      Serial.print("2. Temperature (DHT22): ");Serial.println(dht_temperature);
      Serial.print("3. Heat Index (DHT22): ");Serial.println(dht_heat_index);
      Serial.print("4. Temperature (BMP280): ");Serial.println(bmp_temperature);
      Serial.print("5. Pressure (BMP280): ");Serial.println(bmp_pressure);
      Serial.print("6. Altitude (BMP280): ");Serial.println(bmp_altitude);
      Serial.print("7. Day (RTC): ");Serial.println(rtc_day);
      Serial.print("8. Month (RTC): ");Serial.println(rtc_month);
      Serial.print("9. Year (RTC): ");Serial.println(rtc_year);
      Serial.print("10. Hour (RTC): ");Serial.println(rtc_hour);
      Serial.print("11. Minutes (RTC): ");Serial.println(rtc_minutes);
      Serial.print("12. Seconds (RTC): ");Serial.println(rtc_seconds);
      Serial.print("13. Rain Sensor (Analog): ");Serial.println(rain_sensor_data_analog);
      Serial.print("14. Rain Sesnor (Digital): ");Serial.println(rain_sensor_data_digital);
      Serial.print("15. Rain Guage: ");Serial.println(rain_guage_data);
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

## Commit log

2020-11-19 Added eagle design
    [main.brd, main.sch]
2020-11-19 Added new code
    [main.brd, main.sch]
2020-11-19 Added updated eagle design
    [main.brd, main.sch]
2020-11-19 Added new design and export image
    [main.brd]
2020-11-26 Added support for reed switch and rain sensor
    [main.brd, main.sch]
2020-11-26 Updated PCB export images
2020-11-27 Micro SD Card reader added to eagle design ; New export images added
    [main.brd, main.sch]
2020-12-04 Added CAD files
    [Base.stl, Bucket.stl, Case.stl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]
2020-12-13 Added debug code for arduino nano
2020-12-13 Completed arduino nano code
2020-12-27 Removed cad designs and arduino libraries
    [Base.stl, Bucket.stl, Case.stl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]
2020-12-27 Added STL file links for rain guage and rain sensor support
2021-01-29 Added new code for arduino mega
2021-01-30 Added new eagle design and docs export
    [info.brd, info.sch, main.brd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]
2021-02-05 Added pcb design
    [board.sch, info.brd]
2021-02-06 Addedd new design
    [board.brd, board.sch, info.brd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]
2021-02-07 Added motherboard design and image exports
    [board.brd, board.sch, info.brd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]
2021-02-13 Added new design
    [board.brd, board.sch, info.brd]
2021-02-13 exported board designs
2021-02-14 Added wind direction sensor stl files
    [arrow.stl, body.stl, pvc-holder.stl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]
2021-02-14 Added rain guage stl files
    [base.stl, bucket.stl, case.stl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]
2021-02-21 Added support for Arduino mega
2021-02-23 Updated eagle design
    [board.brd, board.sch]
2021-02-23 Updated PCB exports
2021-02-23 Fixed serial communication pin arduino mega
    [arduino_mega-code.ino]
2021-02-25 Updated eagle data
    [board.brd]
2021-03-02 Updated board design
    Increased track width
    [info.brd]
2021-03-02 new PCB exports
    info board
2021-03-02 Updated bugs
    [info.brd]
2021-03-02 small changes
    [info.brd]
2021-03-02 Updated board design
    [board.brd]
2021-03-02 Exported new board designs

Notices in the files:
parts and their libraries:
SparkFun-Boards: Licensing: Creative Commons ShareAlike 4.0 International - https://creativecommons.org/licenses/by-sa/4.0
